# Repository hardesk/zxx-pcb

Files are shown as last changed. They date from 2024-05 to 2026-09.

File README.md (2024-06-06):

# Caravel with Z80 to DIP40 adapter PCB

See: https://github.com/rejunity/z80-open-silicon

## Pinout

                                   Z80 CPU
                   ,----------------.___.----------------.
      <--    A11  1| io[19] 57                 55 io[18] |40 A10    -->
      <--    A12  2| io[20] 58                 54 io[17] |39 A9     -->
      <--    A13  3| io[21] 59                 53 io[16] |38 A8     -->
      <--    A14  4| io[22] 60                 51 io[15] |37 A7     -->
      <--    A15  5| io[23] 61                 50 io[14] |36 A6     -->
      -->    CLK  6|  XCLK  22                 48 io[13] |35 A5     -->
      <->     D4  7| io[24] 62                 42 io[ 8] |34 A4     -->
      <->     D3  8| io[25]  2                 43 io[ 9] |33 A3     -->
      <->     D5  9| io[26]  3                 44 io[10] |32 A2     -->
      <->     D6 10| io[27]  4                 46 io[12] |31 A1     -->
         VCC_5V0 11|               Caravel     45 io[11] |30 A0     -->
      <->     D2 12| io[28]  5       pins                |29 GND
      <->     D7 13| io[29]  6                 41 io[ 7] |28 /RFSH  -->
      <->     D0 14| io[31]  8                 33 io[ 2] |27 /M1    -->
      <->     D1 15| io[30]  7                 21 io[ 0] |26 /RESET <--
      -->   /INT 16| io[33] 12                 34 io[37] |25 /BUSRQ <--
      -->   /NMI 17| io[32] 11                 37 io[ 6] |24 /WAIT  <--
      <--  /HALT 18| io[34] 31                 32 io[ 1] |23 /BUSAK -->
      <--  /MREQ 19| io[35] 13                 36 io[ 5] |22 /WR    -->
      <--  /IORQ 20| io[36] 14                 35 io[ 4] |21 /RD    -->
                   `-------------------------------------'

## Power rails for Caravel
        GND     29 (Z80) --- vss*               56, 52, 38, 39, 29, 23, 20, 10, 1
        VCC_5V0 11 (Z80) --- vddio              64, 17
        VCC_1V8    (LDO) --- vccd, vccd1, vccd2 63, 49, 18

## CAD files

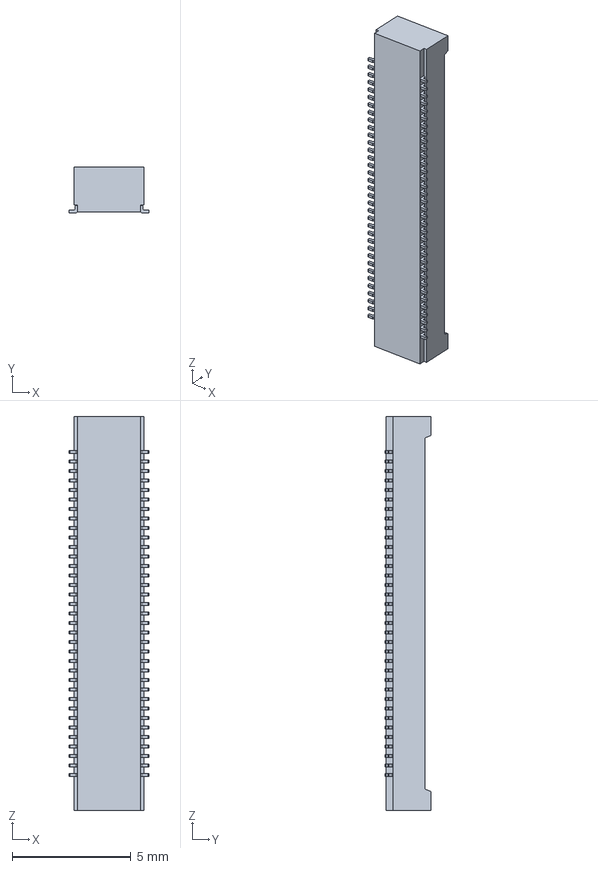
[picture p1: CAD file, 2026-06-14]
mezzanine-dip40/3dmodels/DF40C(2.0)-70DS.stp
3.38 x 1.95 x 16.6 mm

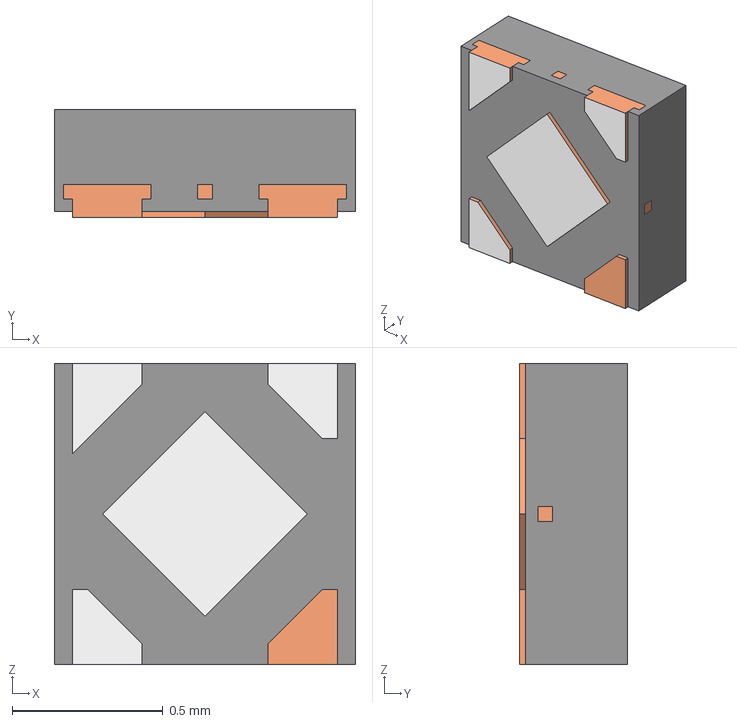
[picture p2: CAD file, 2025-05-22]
z80_qfn64dip/3dmodels/DQN0004A.stp
1.00 x 0.36 x 1.00 mm
MOLD-SNB04A
FRAME-SNB04A

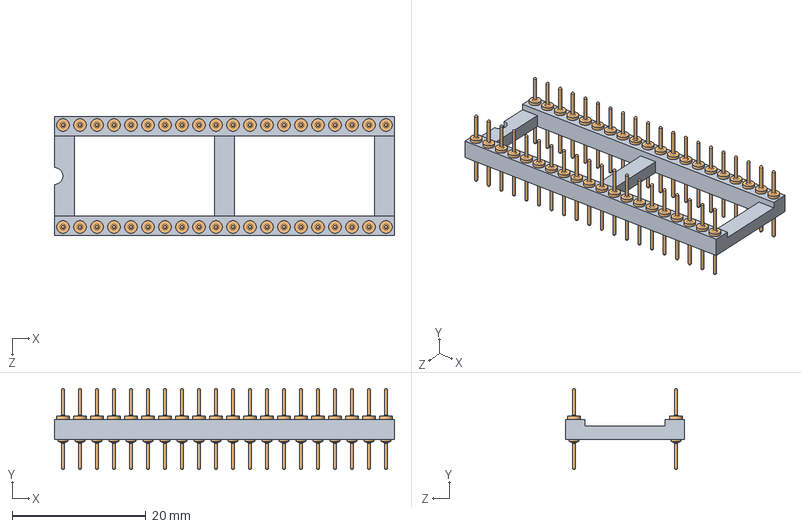
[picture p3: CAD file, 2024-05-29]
z80_qfn64dip/3dmodels/220-1-40-006 3D.STEP
50.8 x 12.1 x 17.8 mm
801-2227P-40-06
802-2227P-GPIN x 40

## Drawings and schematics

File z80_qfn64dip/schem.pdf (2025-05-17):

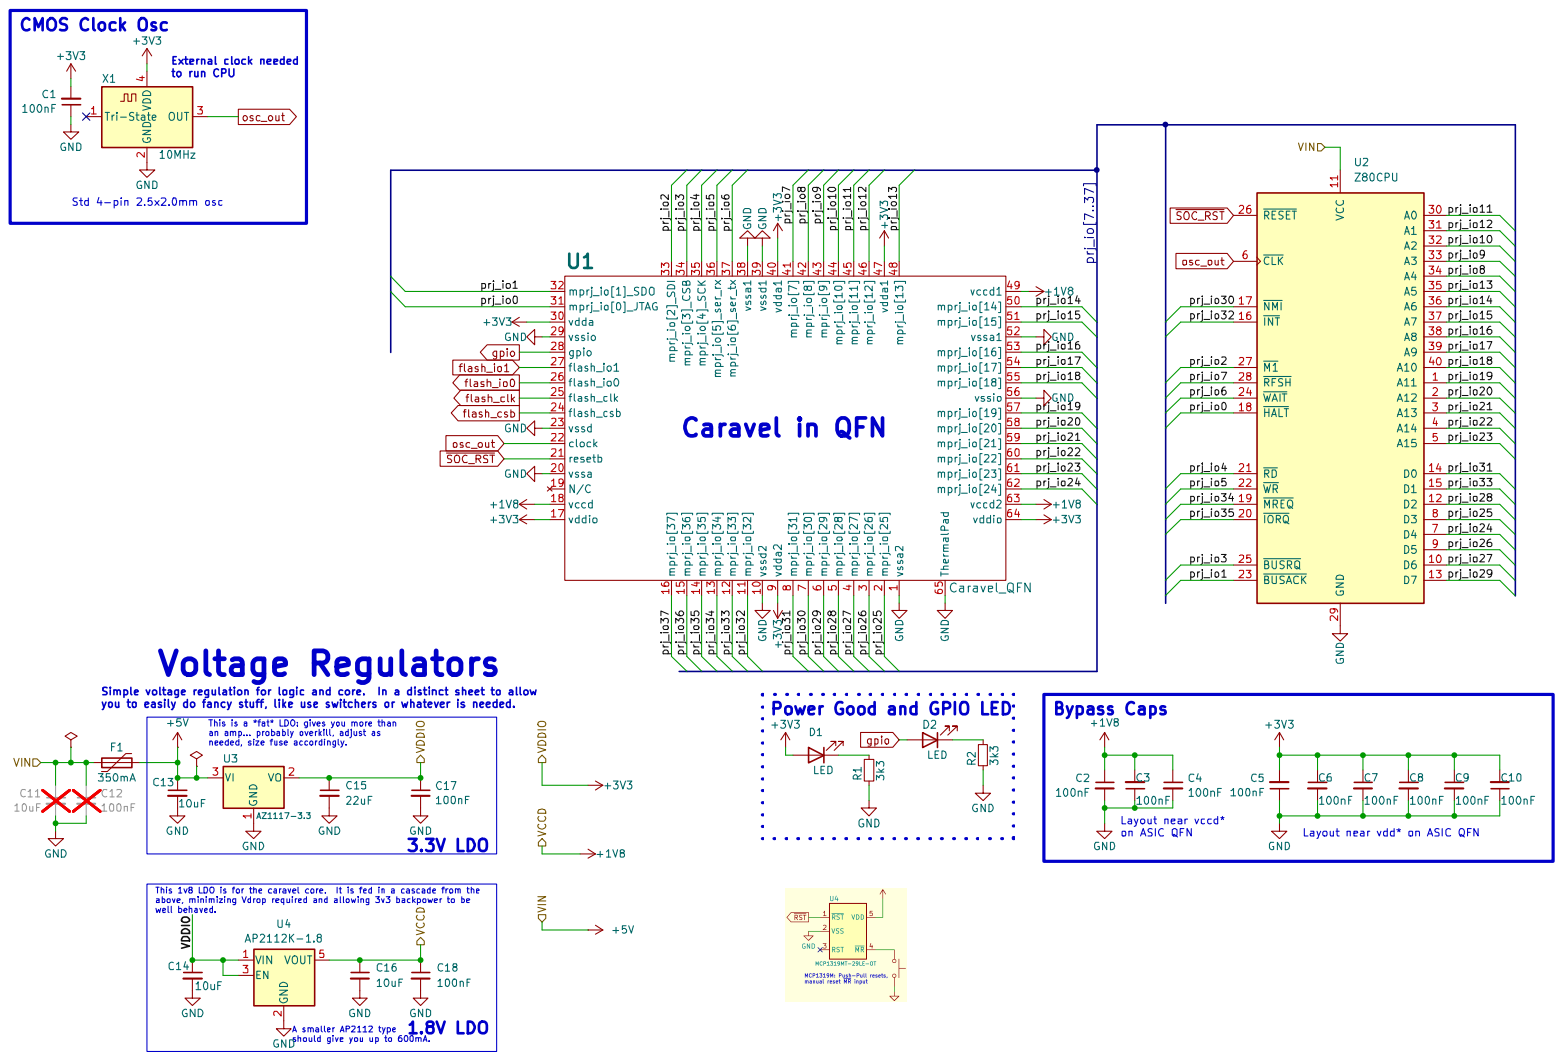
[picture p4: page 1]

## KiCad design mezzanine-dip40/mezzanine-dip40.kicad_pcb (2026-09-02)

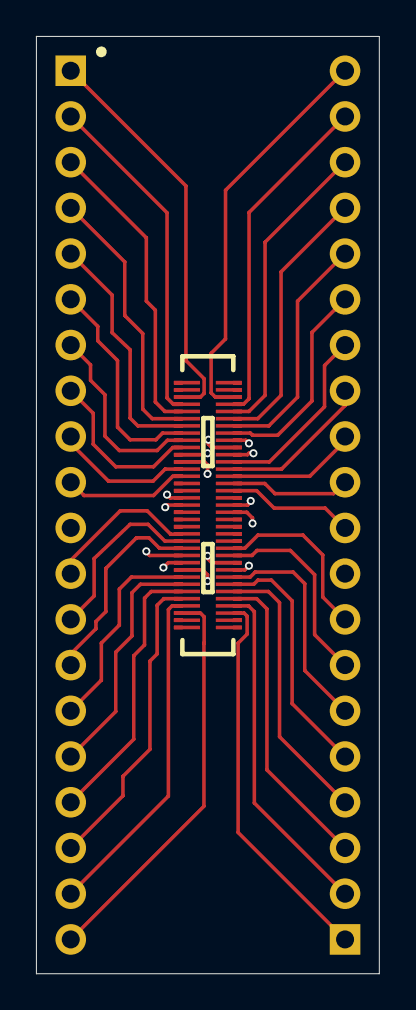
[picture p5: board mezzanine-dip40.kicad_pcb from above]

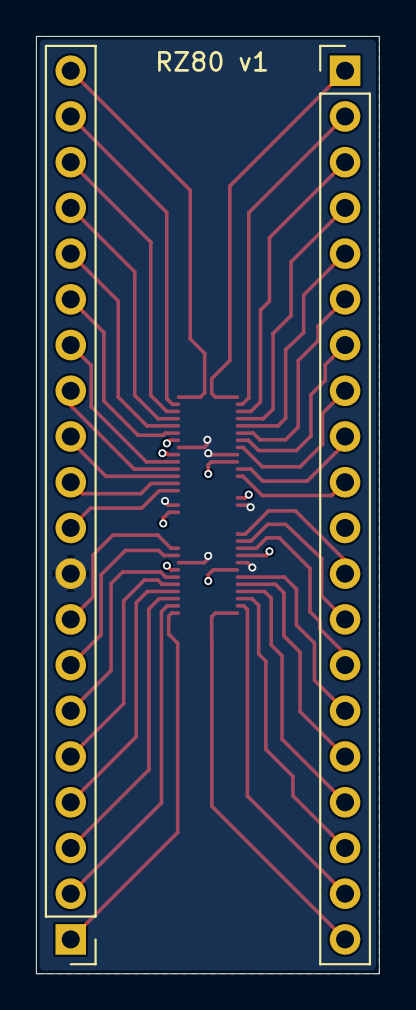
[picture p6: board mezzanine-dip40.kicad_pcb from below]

Board: 4 copper layers, 19.0 x 52.1 mm, 3 parts (2 on the bottom side), 40 nets.

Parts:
J1, J2: Conn_01x20; PinHeader_1x20_P2.54mm_Vertical
U2: CONN-SMD_70P-P0.40_HCTL_HC-PBB40C-70DS-0.4V-xx-02

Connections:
A_{0}: J2.10, U2.51 (pad_28)
A_{1}: J2.11, U2.50 (pad_29)
A_{2}: J2.12, U2.49 (pad_30)
A_{3}: J2.13, U2.48 (pad_31)
A_{4}: J2.14, U2.47 (pad_32)
A_{5}: J2.15, U2.43 (pad_37)
A_{6}: J2.16, U2.42 (pad_38)
A_{7}: J2.17, U2.41 (pad_39)
A_{8}: J2.18, U2.40 (pad_40)
A_{9}: J2.19, U2.39 (pad_41)
A_{10}: J2.20, U2.38 (pad_42)
A_{11}: J1.1, U2.33 (pad_48)
A_{12}: J1.2, U2.32 (pad_49)
A_{13}: J1.3, U2.31 (pad_50)
A_{14}: J1.4, U2.30 (pad_51)
A_{15}: J1.5, U2.29 (pad_52)
CLK: J1.6, U2.28 (pad_53)
D_{0}: J1.14, U2.12 (pad_69)
D_{1}: J1.15, U2.8 (pad_0)
D_{2}: J1.12, U2.14 (pad_67)
D_{3}: J1.8, U2.26 (pad_55)
D_{4}: J1.7, U2.27 (pad_54)
D_{5}: J1.9, U2.23 (pad_58)
D_{6}: J1.10, U2.22 (pad_59)
D_{7}: J1.13, U2.13 (pad_68)
GND: J2.9, U2.10 (GND), U2.18 (GND), U2.25 (GND), U2.45 (GND), U2.53 (GND), U2.61 (GND)
VCC: J1.11, U2.9 (VDD_IO), U2.11 (VDD_CORE), U2.19 (PWR_AUX), U2.24 (VDD_IO), U2.44 (VDD_IO), U2.46 (VDD_CORE), U2.54 (PWR_AUX), U2.62 (VDD_IO)
~BUSACK: J2.3, U2.66 (pad_13)
~BUSRQ: J2.5, U2.64 (pad_15)
~HALT: J1.18, U2.5 (pad_3)
~INT: J1.16, U2.7 (pad_1)
~IORQ: J1.20, U2.3 (pad_5)
~M1: J2.7, U2.60 (pad_19)
~MREQ: J1.19, U2.4 (pad_4)
~NMI: J1.17, U2.6 (pad_2)
~RD: J2.1, U2.68 (pad_11)
~RESET: J2.6, U2.63 (pad_16)
~RFSH: J2.8, U2.59 (pad_20)
~WAIT: J2.4, U2.65 (pad_14)
~WR: J2.2, U2.67 (pad_12)

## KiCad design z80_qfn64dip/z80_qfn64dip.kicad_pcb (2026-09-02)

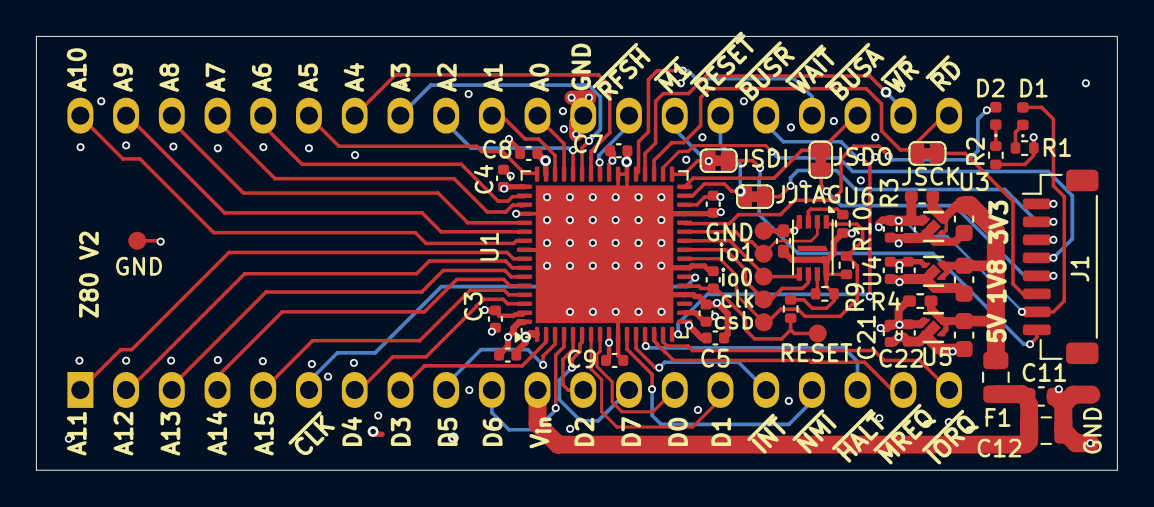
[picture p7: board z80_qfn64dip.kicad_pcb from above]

Board: 4 copper layers, 60.1 x 24.1 mm, 52 parts (0 on the bottom side), 59 nets.

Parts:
C2, C3, C4, C5, C6, C7, C8, C9, C10, C18, C22, C26: 100nF; C_0402_1005Metric
C11: 10uF; C_0805_2012Metric
C12: 100nF; C_0603_1608Metric
C16, C23, C24: 4.7uF; C_0603_1608Metric
C17, C21, C25: 4.7uF; C_0402_1005Metric
C19: 1uF; C_0402_1005Metric
C20: 100nF; C_0402_1005Metric_Pad0.74x0.62mm_HandSolder
D1, D2: LED; LED_0402_1005Metric
F1: 350mA; Fuse_0805_2012Metric
J1: Conn_08; JST_SH_BM08B-SRSS-TB_1x08-1MP_P1.00mm_Vertical
JP1: JSDI; SolderJumper-2_P1.3mm_Bridged_RoundedPad1.0x1.5mm_Small_Mar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
JP2: JSCK; SolderJumper-2_P1.3mm_Bridged_RoundedPad1.0x1.5mm_Small_Mar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
JP3: JJTAG; SolderJumper-2_P1.3mm_Bridged_RoundedPad1.0x1.5mm_Small_Mar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
JP5: JSDO; SolderJumper-2_P1.3mm_Bridged_RoundedPad1.0x1.5mm_Small_Mar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
R1, R2: 4k7; R_0402_1005Metric
R3, R4: 0R; R_0402_1005Metric_Pad0.72x0.64mm_HandSolder
R9, R10, R11, R12: 10k; R_0402_1005Metric
TP9: io1; TestPoint_Pad_D1.0mm
TP10: io0; TestPoint_Pad_D1.0mm
TP11: clk; TestPoint_Pad_D1.0mm
TP12: csb; TestPoint_Pad_D1.0mm
TP13: GND; TestPoint_Pad_D1.0mm
TP14: RESET; TestPoint_Pad_D1.0mm_Small_Margin
TP15, TP16: GND; TestPoint_Pad_D1.0mm_Small_Margin
U1: Caravel_QFN; QFN-64-1EP_9x9mm_P0.5mm_EP7.65x7.65mm
U2: Z80CPU; IC_ADAPTER_ 220-1-40-006
U3: TPS7A2033PDQNRM3; DQN0004A-MFG
U4: TPS7A2018PDQNRM3; DQN0004A-MFG
U5: TPS7A2050PDQNRM3; DQN0004A-MFG
U6: AT25EU0081A; UDFN-8-1EP-2x3mm_P0.5mm_EP1.6x0.2mm

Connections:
/HKJTAG: J1.2, JP3.2 (B)
/HKSCK: J1.6, JP2.2 (B)
/HKSDI: J1.8, JP1.2 (B)
/HKSDO: J1.5, JP5.1 (A)
/VIN: C11.1, C12.1, F1.1, U2.11 (VCC)
/VIN_{F}: C16.1, C23.1, C24.1, F1.2, R3.1, R4.1, U3.3 (EN), U3.4 (IN), U4.3 (EN), U4.4 (IN), U5.3 (EN), U5.4 (IN)
/prj_io7: U1.41 (mprj_io[7]), U2.28 (~RFSH)
/prj_io8: U1.42 (mprj_io[8]), U2.34 (A4)
/prj_io9: U1.43 (mprj_io[9]), U2.33 (A3)
/prj_io10: U1.44 (mprj_io[10]), U2.32 (A2)
/prj_io11: U1.45 (mprj_io[11]), U2.30 (A0)
/prj_io12: U1.46 (mprj_io[12]), U2.31 (A1)
/prj_io13: U1.48 (mprj_io[13]), U2.35 (A5)
/prj_io14: U1.50 (mprj_io[14]), U2.36 (A6)
/prj_io15: U1.51 (mprj_io[15]), U2.37 (A7)
/prj_io16: U1.53 (mprj_io[16]), U2.38 (A8)
/prj_io17: U1.54 (mprj_io[17]), U2.39 (A9)
/prj_io18: U1.55 (mprj_io[18]), U2.40 (A10)
/prj_io19: U1.57 (mprj_io[19]), U2.1 (A11)
/prj_io20: U1.58 (mprj_io[20]), U2.2 (A12)
/prj_io21: U1.59 (mprj_io[21]), U2.3 (A13)
/prj_io22: U1.60 (mprj_io[22]), U2.4 (A14)
/prj_io23: U1.61 (mprj_io[23]), U2.5 (A15)
/prj_io24: U1.62 (mprj_io[24]), U2.7 (D4)
/prj_io25: U1.2 (mprj_io[25]), U2.8 (D3)
/prj_io26: U1.3 (mprj_io[26]), U2.9 (D5)
/prj_io27: U1.4 (mprj_io[27]), U2.10 (D6)
/prj_io28: U1.5 (mprj_io[28]), U2.12 (D2)
/prj_io29: U1.6 (mprj_io[29]), U2.13 (D7)
/prj_io30: U1.7 (mprj_io[30]), U2.15 (D1)
/prj_io31: U1.8 (mprj_io[31]), U2.14 (D0)
/prj_io32: U1.11 (mprj_io[32]), U2.17 (~NMI)
/prj_io33: U1.12 (mprj_io[33]), U2.16 (~INT)
/prj_io34: U1.13 (mprj_io[34]), U2.18 (~HALT)
/prj_io35: U1.14 (mprj_io[35]), U2.19 (~MREQ)
/prj_io36: U1.15 (mprj_io[36]), U2.20 (~IORQ)
/prj_io37: U1.16 (mprj_io[37]), U2.25 (~BUSRQ)
GND: C2.2, C3.1, C4.2, C5.1, C6.2, C7.2, C8.2, C9.2, C10.1, C11.2, C12.2, C16.2, C17.2, C18.2, C19.2, C20.2, C21.2, C22.2, C23.2, C24.2, C25.2, C26.2, J1.1, J1.3, R1.2, R2.2, TP13.1, TP15.1, TP16.1, U1.1 (vssa2), U1.10 (vssd2), U1.20 (vssa), U1.23 (vssd), U1.29 (vssio), U1.38 (vssa1), U1.39 (vssd1), U1.52 (vssa1), U1.56 (vssio), U1.65 (ThermalPad), U2.29 (GND), U3.2 (GND), U3.5 (Thermal_Pad), U4.2 (GND), U4.5 (Thermal_Pad), U5.2 (GND), U5.5 (Thermal_Pad), U6.4 (GND)
HK_CSB: J1.4, U1.34 (mprj_io[3]_CSB)
HK_JTAG: JP3.1 (A), U1.31 (mprj_io[0]_JTAG), U2.26 (~RESET)
HK_SCK: JP2.1 (A), U1.35 (mprj_io[4]_SCK), U2.21 (~RD)
HK_SDI: JP1.1 (A), U1.33 (mprj_io[2]_SDI), U2.27 (~M1)
HK_SDO: JP5.2 (B), U1.32 (mprj_io[1]_SDO), U2.23 (~BUSACK)
unnamed: D1.1 (K), R1.1
unnamed: D2.1 (K), R2.1
unnamed: R11.1, U6.7 (~HOLD(IO_{3}))
unnamed: R10.1, U6.3 (~WP(IO_{2}))
VCCD: C2.1, C3.2, C4.1, C17.1, C18.1, U1.18 (vccd), U1.49 (vccd1), U1.63 (vccd2), U4.1 (OUT)
VDDA: C6.1, C7.1, C8.1, C9.1, C20.1, C25.1, C26.1, D1.2 (A), J1.7, R3.2, R9.1, R10.2, R11.2, R12.1, U1.9 (vdda2), U1.30 (vdda), U1.40 (vdda1), U1.47 (vdda1), U3.1 (OUT), U6.8 (Vcc)
VDDIO: C5.2, C10.2, C21.1, C22.1, R4.2, U1.17 (vddio), U1.64 (vddio), U5.1 (OUT)
flash_clk: TP11.1, U1.25 (flash_clk), U6.6 (SCK)
flash_csb: R9.2, TP12.1, U1.24 (flash_csb), U6.1 (~CS)
flash_io0: TP10.1, U1.26 (flash_io0), U6.5 (SI(IO_{0}))
flash_io1: TP9.1, U1.27 (flash_io1), U6.2 (SO(IO_{1}))
gpio: D2.2 (A), U1.28 (gpio)
osc_out: U1.22 (clock), U2.6 (~CLK)
ser_rx: U1.36 (mprj_io[5]_ser_rx), U2.22 (~WR)
ser_tx: U1.37 (mprj_io[6]_ser_tx), U2.24 (~WAIT)
~SOC_RST: C19.1, R12.2, TP14.1, U1.21 (resetb)

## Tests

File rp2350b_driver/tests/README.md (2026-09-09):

# WAIT bus regression

The hardware trace test requires `request.dump()` enabled in the main loop,
before `write_reply()`. Normal firmware may leave that call commented out.
RTT uses blocking mode, so a stopped debugger can hold a request indefinitely.
The bus PIO must keep WAIT asserted and issue exactly one request per transfer.

The revised 32-word PIO program:

- Qualifies `(MREQ || IORQ) && (RD || WR)` from one GPIO image, testing
  MREQ/IORQ first. A second qualified sample after another clock supplies the
  request, with WAIT asserted throughout.
- Sets read data and direction before releasing WAIT at a settled falling
  clock phase. The independent clock SM keeps running during logging.
- Checks MREQ, IORQ, RD and WR together, continuously, until **two consecutive
  samples** show all four inactive. It then releases data and re-arms WAIT.
  A single strobe transition, including WR pulses during Tw, cannot end a cycle.

Do not replace completion detection with one sample per clock: the inactive
gap around refresh can last only half a clock. The GPIO/DMA capture caught
that approach missing the gap, leaving WAIT high through the next operand read.
Do not deduplicate by address: two legitimate reads may use the same address.

The `[15]` delays assume the board's 150 MHz system clock and allow the Tang
external-clock synchronizer to settle. The driver requires at least 40 PIO
ticks per Z80 clock (up to 3.75 MHz at 150 MHz). This is a board timing budget,
not a claim of compatibility with every external Z80 implementation.

## Instruction-level regression

```sh
make test-wait-pio
```

The test interprets the actual PIO source. It checks 42 clock phases and eight
reply delays, with startup reset, refresh rejection, short strobe glitches,
WR pulses during waits, read/write turnaround, I/O, and repeated-address reads.
It checks request count, data direction, data setup, and WAIT re-arming.
This digital model does not model FPGA propagation delay or metastability.

## Hardware regression

Before building the hardware test, enable `request.dump()` in `main.cpp`, set
`prog_org` to `0x100`, and select the stress program in `CMakeLists.txt`:

```cmake
set(DATA_ASM ${CMAKE_CURRENT_SOURCE_DIR}/tests/wait_bus_stress.asm)
```

Replace the existing active `DATA_ASM` selection for this test. An unconditional
`set(DATA_ASM ...)` overrides a command-line `-DDATA_ASM=...` cache value.
Keep these test-only source changes out of the normal firmware commit, and use
a separate build directory:

```sh
cmake -S . -B derived/wait_regression \
  -DPICO_SDK_PATH=/Users/orl/Projects/pico-sdk \
  -DCMAKE_BUILD_TYPE=Release -DZ80_BUS_MODE=WAIT \
  -DZ80_CLOCK_HZ=3500000 -DZ80_REPLY_DELAY_US=0
cmake --build derived/wait_regression --parallel
```

Run `make openocd` in another terminal. The following command **flashes the
attached RP2350**, verifies it, resets it, and captures RTT. No FPGA bitstream
is changed.

```sh
python3 tests/capture_wait_trace.py \
  derived/wait_regression/rp2350_driver.elf \
  derived/wait_regression/trace.log \
  --seconds 45 --pause-every 2 --pause-seconds 0.5 --poll-ms 1
python3 tests/check_wait_trace.py \
  derived/wait_regression/wait_bus_stress.bin \
  derived/wait_regression/trace.log
```

Pauses stop **OpenOCD RTT polling**, rather than just TCP reads, so socket
buffers cannot hide the intended blocking-printf stall. All complete trace
lines are checked from the reset vector onwards. The checker compares address,
M1, request/transfer controls, memory contents and write data with an independent
execution of the small stress program. Conditional branches also check that the
CPU actually received the read data. Each loop has 65 bus requests and includes
two reads of the same memory location, memory writes and I/O reads/writes.

Set `-DZ80_REPLY_DELAY_US=10000` to add a deterministic varying 0–10 ms delay
before every reply. Use `-DZ80_WAIT_CAPTURE=ON` to capture GPIO0..31 with PIO2
and DMA around the first eight replies; `sample` indices are four system-clock
ticks apart (26.67 ns at 150 MHz). Captures perturb host reply timing and are
diagnostics, not the final stress qualification. Capture records are ignored
by the bus-trace checker.

Restore the normal program selection, load address and logging setting, then
rebuild and reflash the normal firmware after testing. See `wait_results.md` for the
recorded board results and remaining validation limits.

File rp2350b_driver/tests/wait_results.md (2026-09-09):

# Board results — 2026-09-08

Tests used the attached RP2350/CMSIS-DAP board, the existing FPGA configuration,
150 MHz RP2350 system clock, WAIT backend, and blocking `request.dump()` before
every reply. The FPGA was not reprogrammed. Raw traces and test ELFs are in
`derived/wait_stress/` (build artifacts, not source-controlled).

The starting PIO failed at request 2 in `baseline.log`:

```text
busreq 0000 55 m1 1 mreq 1 ioreq 0 rd 1 wr 0 mem c3
busreq 0000 c3 m1 0 mreq 1 ioreq 0 rd 1 wr 0 mem c3
```

The second request should have been the operand at `0001`. Adding a second
qualification sample alone also failed (request 208, `settle.log`). A version
that sampled cycle completion once per clock skipped transfers; the DMA trace
in `aligned_capture.log` shows WAIT remaining high through the `0001` read
after the reset opcode reply. That experiment was rejected.

The final program uses continuous, coherent, twice-confirmed idle detection
and keeps the extra qualification sample and clock-aligned reply release.
The trace checker passed these runs with no extra/missing requests, incorrect
controls, or incorrect memory/write data:

| Build / Z80 clock | Host delay | Checked requests | Complete loops | Trace |
|---|---|---:|---:|---|
| Release / 3.5 MHz | RTT pauses of 250 ms | 3,734 | 57 | `continuous_end.log` |
| Release / 3.5 MHz | RTT pauses of 500 ms, 45 s run | 73,721 | 1,134 | `final_3500k.log` |
| Release / 3.5 MHz | Varying 0–10 ms per reply + 500 ms RTT pauses | 4,888 | 75 | `final_delay10ms.log` |
| Release / 100 kHz | RTT pauses of 500 ms | 34,529 | 531 | `final_100k.log` |
| Debug / 3.75 MHz | RTT pauses of 500 ms | 41,314 | 635 | `final_3750k_debug.log` |

Total: **158,186 checked requests, 2,432 complete loops**. Each trace starts
from a fresh verified firmware flash/reset; no trace prefix was discarded.

The source-interpreting PIO regression also passed all 336 reply-delay/clock-
phase combinations. It is a digital handshake test, not an electrical model.

Finally, `derived/drv_dbg/rp2350_driver.elf` was rebuilt, flashed and verified
with the original ZEXALL image, Debug, 3.5 MHz, zero injected reply delay and
GPIO capture disabled. Its generated PIO instructions match the stress-tested
program. `normal_zexall.log` records 20,762 requests, the correct reset-vector
sequence, and the ZEXALL startup banner. The main-loop dump was enabled for
that recorded run.

These tests validate memory fetch/read/write and I/O read/write under delayed
replies. They do not constitute a complete ZEXALL run or an interrupt-acknowledge,
physical BUSRQ/DMA, or reset-during-transaction qualification.

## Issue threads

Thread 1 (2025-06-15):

Questions about circuit

psychogenic, 2025-06-15:
Greets,
At Rej's request, I'm doing a mini review and proto run of these boards.  I have to look back at the old caravel boards to make sure that that "poor man's" reset circuit (a cap) was actually working w/o explicit pull-up (I think there's an internal, will check).  It's all a bit fuzzy (haven't played with caravel in a while) but the two first things that popped out to me are:

  *  I've never pushed VDDIO to the abs max of 5V--you know this is ok, or are just sticking to the fact that it's the listed maximum?  an
  *  If VDDIO is 5V, are we certain the pins going to the external flash are running at VDDA of 3v3?

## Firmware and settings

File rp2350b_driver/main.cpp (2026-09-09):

#include <cstddef>
#include <cstdint>
#include <cstring>
#include <cstdio>
#include <algorithm>
// #include <memory>

#include <pico/stdlib.h>
#include <pico/stdio.h>
#include <hardware/gpio.h>

#include "z80_pins.hpp"
#include "z80_pio_bus.hpp"
#ifdef Z80_WAIT_CAPTURE
#include "tests/wait_capture.hpp"
#endif

using std::size_t;

#define PIN_DEBUG 1

#define IO_DATA_SHIFT 0
#define IO_DATA 0x0000'00ffu
#define IO_ADDR_SHIFT 8
#define IO_ADDR 0x00ff'ff00u
#define IO_CTRL 0x1f'ff00'0000ull
#define IO_CTRL_SHIFT 24
#define IO_CTRLL_WIDTH 8
#define IO_CTRLH_WIDTH 5
#define IO_ALL ((uint64_t)IO_DATA|(uint64_t)IO_ADDR|(uint64_t)IO_CTRL)

inline uint32_t extract_ctrl(uint64_t ctrl_addr_data) {
    return (ctrl_addr_data & IO_CTRL) >> IO_CTRL_SHIFT;
}

inline uint32_t extract_ctrl(uint32_t ctrl_addr_data, uint32_t ctrlhi) {
    uint32_t lo = (ctrl_addr_data & IO_CTRL) >> IO_CTRL_SHIFT;
    uint32_t hi = ctrlhi & (IO_CTRL >> 32);
    return lo | (hi << IO_CTRLL_WIDTH);
}

struct ZxDbgPins
{
    uint16_t addr;
    uint8_t data;
    union {
        struct {
            bool CLK:1, RESET:1, WAIT:1, M1:1, MREQ:1, IORQ:1, RD:1, WR:1,
                 INT:1, NMI:1, BUSREQ:1, BUSACK:1, HALT:1;
        };
        uint16_t value;
    } pins;

    ZxDbgPins(uint32_t lo, uint32_t hi) {
        addr = (lo & IO_ADDR) >> IO_ADDR_SHIFT;
        data = (lo & IO_DATA) >> IO_DATA_SHIFT;
        pins.value = extract_ctrl(lo, hi);
    }

    ZxDbgPins(uint64_t v) {
        addr = (v & IO_ADDR) >> IO_ADDR_SHIFT;
        data = (v & IO_DATA) >> IO_DATA_SHIFT;
        pins.value = extract_ctrl(v);
    }

    void dump_state(unsigned T) {
        printf("T%4d %04x %02x clk %d rst %d mreq %d m1 %d iorq %d rd %d wr %d int %d halt %d wait %d nmi %d busreq %d busack %d\n",
            T, addr, data,
            pins.CLK, pins.RESET, pins.MREQ, pins.M1, pins.IORQ, pins.RD, pins.WR,
            pins.INT, pins.HALT, pins.WAIT, pins.NMI, pins.BUSREQ, pins.BUSACK
        );
    }
};

template<class DerivedT>
struct ZxEnv
{
    // typedef uint8_t (*f_io_read_t)(uint16_t addr);
    // typedef void (*f_io_write_t)(uint16_t addr, uint8_t data);

    DerivedT& self() { return *static_cast<DerivedT*>(this); }

    char* m_ram;
    size_t m_ram_size;

    #define DAT(x) ((addr_data&IO_DATA)>>IO_DATA_SHIFT)
    #define ADR(x) ((addr_data&IO_ADDR)>>IO_ADDR_SHIFT)

    #define IS_LO(pin,bits) ((bits & (1U<<(pin-IO_CTRL_SHIFT))) == 0)
    #define IS_HI(pin,bits) ((bits & (1U<<(pin-IO_CTRL_SHIFT))) != 0)

    uint16_t m_ctrl_prev = (uint16_t)(IO_CTRL>>IO_CTRL_SHIFT);

    uint8_t peek(uint16_t addr) const { return m_ram[addr]; }

    // ctrl is shifted to 0 bits
    void react(uint16_t ctrl, uint32_t addr_data) {
        uint32_t ctrlx = m_ctrl_prev ^ ctrl; // =1 which signal changed
        m_ctrl_prev = ctrl;

        // MEMORY ACCESS
        if (IS_LO(pMREQ, ctrl)) {
            // CPU WRITEs
            if (IS_LO(pWR, ctrl) && IS_HI(pWR, ctrlx)) {
                uint16_t addr = ADR(addr_data);
                uint8_t dat = DAT(addr_data);
                self().impl_debug_trap(addr, dat);
                self().impl_on_memwrite(addr, dat);
                m_ram[addr] = dat;
            } else
            // CPU READs
            if (IS_LO(pRD, ctrl) && IS_HI(pRD, ctrlx)) {
                uint16_t addr = ADR(addr_data);
                uint8_t dat = m_ram[addr];
                self().impl_on_memread(addr, IS_LO(pM1, ctrl));
                if (IS_LO(pM1, ctrl)) {
                    // printf("\033[34mcode %04x %02x\033[0m\n", addr, dat);
                    if (addr==0)
                        printf("\033[31mSOFT RESET DETECTED\033[0m\n");
                }
                self().expose_data(dat);
            }
        } else
        // CPU done reading/writing memory
        if (IS_HI(pMREQ, ctrl) && IS_HI(pMREQ, ctrlx)) {
            self().clear_data_bus();
        }
        // IO ACCESS
        if (IS_LO(pIORQ, ctrl)) {
            // CPU WRITEs IO
            if (IS_LO(pWR, ctrl) && IS_HI(pWR, ctrlx)) {
                uint16_t addr = ADR(addr_data);
                uint8_t dat = DAT(addr_data);
                self().handle_io_out(addr, dat);
            } else
            // CPU READs IO
            if (IS_LO(pRD, ctrl) && IS_HI(pRD, ctrlx)) {
                uint16_t addr = ADR(addr_data);
                uint8_t dat = self().handle_io_in(addr);
                self().expose_data(dat);
            }
        } else
        // CPU done reading/writing IO
        if (IS_HI(pIORQ, ctrl) && IS_HI(pIORQ, ctrlx)) {
            self().clear_data_bus();
        }
    }

    struct MemoryDumpOpts {
        short width = 16;
        bool show_address:1 = true;
        bool ascii:1 = false;
    };

    void dump_memory(unsigned addr, size_t size, MemoryDumpOpts opts = MemoryDumpOpts()) {
        for (size_t i=0; i<size; ) {
            char const* pl = m_ram + addr + i;
            size_t mx = std::min(size-i, (size_t)opts.width);
            if (opts.show_address)
                printf("%08x  ", addr + i);
            for (size_t q=0; q<mx; ++q)
                printf("%02x%s", pl[q], q == mx-1 ? "" : " ");
            printf("%*s", 1 + (opts.width-mx)*3, "");
            if (opts.ascii) {
                printf("%c", ' ');
                for (size_t q=0; q<mx; ++q)
                    printf("%c", pl[q] >= 32 && pl[q] <= 127 ? pl[q] : '.' );
            }
            printf("\n");
            i += mx;
        }
    }

protected:
    void impl_debug_trap(uint16_t addr, uint8_t trapno) {}

    void impl_on_memread(uint16_t addr, bool m1) {}
    void impl_on_memwrite(uint16_t addr, uint8_t dat) {}
};

struct Rp2350ZxEnv : public ZxEnv<Rp2350ZxEnv>
{
    template<class T> friend class ZxEnv;

    Rp2350ZxEnv() {
        m_ram_size = 256*256;
        m_ram = new char[m_ram_size];
        memset(m_ram, 0, m_ram_size);
    }

    ~Rp2350ZxEnv() {
        delete[] m_ram;
    }
    
    static constexpr uint64_t kInitialHighPins =
        (1ull << pINT) | (1ull << pWAIT) | (1ull << pNMI) | (1ull << pBUSRQ);
    static constexpr uint16_t CPM_TRAP_TRIGGER = 0x03;
    static constexpr uint16_t CPM_TRAP_CODE = 0xffe0; // Note: zexall sets SP to address at (6)
    static constexpr uint16_t CPM_TRAP_STORE = 0xfff0;

    void init() {
        uint64_t pins_oe = 
            (1ull << pCLK)     |
            (1ull << pRESET)   |
            (1ull << pINT)     |
            (1ull << pWAIT)    |
            (1ull << pNMI)     |
            (1ull << pBUSRQ) 
            ;
        for(int i=0; i<pPIN_COUNT; ++i)
            gpio_set_pulls(i, false, false);
        gpio_set_function_masked64(IO_ALL, GPIO_FUNC_SIO);

        // Set the output latches before enabling them. RESET and CLK start
        // low; interrupt inputs, WAIT and BUSRQ start inactive (high).
        gpio_put_all64(kInitialHighPins);
        gpio_set_dir_all_bits64(pins_oe);
    }

    void expose_data(uint8_t dat) {
        // gpio_set_dir_out_masked(IO_LOW_OUT | IO_DATA);
        gpio_set_dir_masked(IO_DATA, IO_DATA);
        gpio_put_masked(IO_DATA, dat << IO_DATA_SHIFT);
    }

    void clear_data_bus() {
        // gpio_set_dir_out_masked(IO_LOW_OUT);
        gpio_set_dir_masked(IO_DATA, 0);
    }

    void handle_io_out(uint16_t addr, uint8_t data) {
        if (addr == 0xff81) {
            printf("DATA on port %04x: %02x\n", addr, data);
        } else if (addr == 0xff83) {
            printf("%c", data);
        }
    }
    uint8_t handle_io_in(uint16_t port) {
        return (port & 1) ? 0xFF : 0xBF;
    }

    uint8_t handle_interrupt_ack() { return 0xff; }

    uint32_t service_pio_request(z80pio::BusRequest const& request) {
        const uint16_t addr = request.address();
        const uint8_t data = request.data();

        if (request.mreq() && request.rd()) {
            uint8_t value = static_cast<uint8_t>(m_ram[addr]);
            impl_on_memread(addr, request.m1());
            return z80pio::read_reply(value);
        }

        if (request.mreq() && request.wr()) {
            impl_debug_trap(addr, data);
            impl_on_memwrite(addr, data);
            m_ram[addr] = static_cast<char>(data);
            return z80pio::write_reply();
        }

        if (request.iorq() && request.rd())
            return z80pio::read_reply(handle_io_in(addr));

        if (request.iorq() && request.wr()) {
            handle_io_out(addr, data);
            return z80pio::write_reply();
        }

        if (request.iorq() && request.m1())
            return z80pio::read_reply(handle_interrupt_ack());

        return z80pio::write_reply();
    }

    template<class... Bytes>
    static char* store_bytes(char* p, Bytes... bytes) { ( (*p++ = bytes), ... ); return p; }

    void prepare_vectors(uint16_t jump_on_reset_addr = 0x100) {
        store_bytes( m_ram + 0, 0xc3, jump_on_reset_addr & 0xff, jump_on_reset_addr >> 8);
        store_bytes( m_ram + CPM_TRAP_TRIGGER, 0, 0);

        // hook up to CP/M call 5
        store_bytes(m_ram + 5, 0xc3, CPM_TRAP_CODE, CPM_TRAP_CODE >> 8);    // jp CPM_TRAP_CODE

        // by default 0x100 jumps to 0x8000
        store_bytes(m_ram + 0x100, 0xc3, 0x00, 0x80);    // jp 0x8000

        char* p = m_ram + CPM_TRAP_CODE;
        p = store_bytes(p, 0xed, 0x43, CPM_TRAP_STORE, CPM_TRAP_STORE >> 8);    // ld (CPM_TRAP_STORE+0), bc
        p = store_bytes(p, 0xed, 0x53, CPM_TRAP_STORE+2, CPM_TRAP_STORE >> 8);  // ld (CPM_TRAP_STORE+2), de
        p = store_bytes(p, 0x3e, 0x01);                                 // ld a, 1
        p = store_bytes(p, 0x32, CPM_TRAP_TRIGGER, CPM_TRAP_TRIGGER >> 8);      // ld (CPM_TRAP_TRIGGER), a <-- trigger trap
        p = store_bytes(p, 0xc9);                                       // ret
    }

    void load(unsigned char const* data, size_t size, uint16_t origin) {
        unsigned char* dest = (unsigned char*)m_ram + origin;
        memcpy(dest, data, size);
    }

private:
    void impl_debug_trap(uint16_t addr, uint8_t trapno) {
        if (addr == 4) {
            printf("MEM4 <- %02x\n", trapno);
        }
        if (addr == CPM_TRAP_TRIGGER && trapno == 1) {
            uint8_t c = *(m_ram+CPM_TRAP_STORE+0);
            uint16_t de = *(uint16_t*)(m_ram+CPM_TRAP_STORE+2);
            if (c == 2) {
                uint8_t e = de&0xff;
                printf("%c", e);
            } else if (c==9) {
                char const* str = (char const*)m_ram + de;
                while (*str != '$' && *str != 0) {
                    printf("%c", *str++);
                }
            }
        }
    }

    void impl_on_memwrite(uint16_t addr, uint8_t dat) {
        // if (addr >= 0x1d30 && addr <= 0x1db8) {
        //     printf(">> writing %02x to %04x\n", dat, addr);
        //     dump_memory(0x1d00, 256, { .width = 8, .show_address = true, .ascii = true } );
        // }
    }

};

inline static uint32_t gpio_get_all_hi() {
#if PICO_USE_GPIO_COPROCESSOR
    return gpioc_hi_in_get();
#elif NUM_BANK0_GPIOS <= 32
    return 0;
#else
    return sio_hw->gpio_hi_in;
#endif
}

#define LED_PIN (32+14)

constexpr uint kZ80ResetButtonPin = 40;

void init_z80_reset_button()
{
    gpio_init(kZ80ResetButtonPin);
    gpio_set_dir(kZ80ResetButtonPin, GPIO_IN);
    gpio_pull_up(kZ80ResetButtonPin);
}

bool z80_reset_button_pressed()
{
    return !gpio_get(kZ80ResetButtonPin);
}

void blink_hello() {
    for(size_t i=0; i<10; ++i) {
        gpio_put(LED_PIN, (i&1) == 0);
        sleep_ms(50);
    }
}

struct DebButton {
    static constexpr unsigned POLL_MS = 10;
    DebButton() : next_poll(make_timeout_time_ms(POLL_MS)), last_sample(false), debounced(false) {
    }

    template<class F>
    bool check( F f ) {
        bool pressed = false;
        if (time_reached(next_poll)) {
            next_poll = make_timeout_time_ms(POLL_MS);
            const bool sample = f();
            if (sample == last_sample && sample != debounced)
                pressed = debounced = sample;
            last_sample = sample;
        }
        return pressed;
    }

private:
    absolute_time_t next_poll = 0;
    bool last_sample:1;
    bool debounced:1;
};

#ifdef DATA_ASM_FILE

#if __has_include(DATA_ASM_FILE)
#include DATA_ASM_FILE
#define z80_prog DATA_ASM_LABEL
#endif

#else 

// #if __has_include("zexdoc.h")
// #include "zexdoc.h"
// #define z80_prog zexdoc_prog
// #endif

#if __has_include("test.h")
#include "test.h"
#define z80_prog test_prog
#endif

#endif

// unsigned char copy_str_code[] = {
//   0x11, 0xc0, 0x00, 0x21, 0x0e, 0x01, 0x7e, 0x12, 0x13, 0x23, 0xb7, 0x20,
//   0xf9, 0xc9, 0x48, 0x65, 0x6c, 0x6c, 0x6f, 0x20, 0x57, 0x6f, 0x72, 0x6c,
//   0x64, 0x21, 0x00
// };

int main()
{
    stdio_init_all();

    gpio_set_dir(LED_PIN, true);
    gpio_set_function(LED_PIN, GPIO_FUNC_SIO);
    blink_hello();

    Rp2350ZxEnv zx;
    zx.init();
    init_z80_reset_button();

    // uint16_t prog_org = 0x8000;
    uint16_t prog_org = 0x100;
    zx.prepare_vectors(prog_org);
    zx.load(z80_prog, count_of(z80_prog), prog_org);
    zx.dump_memory(0, 32, { .width = 16, .ascii = true } );
    zx.dump_memory(prog_org, 64, { .width = 16, .ascii = true } );

    printf("Hello from RP2350 over RTT!\n");
    char buf[128];
    auto fmt_pad = [&buf](uint32_t pad) {
        #define GB(x, def) ((x & PADS_BANK0_GPIO0_ ## def ## _BITS) >> PADS_BANK0_GPIO0_ ## def ## _LSB)
        snprintf(buf, sizeof(buf), "iso %d od %d ie %d drive %d pue %d pde %d schmitt %d slewfast %d",
            GB(pad, ISO),
            GB(pad, OD),
            GB(pad, IE),
            GB(pad, DRIVE),
            GB(pad, PUE),
            GB(pad, PDE),
            GB(pad, SCHMITT),
            GB(pad, SLEWFAST));
        return buf;
    };

    // printf("pins oe hi %08x lo %08x func-A0 %d outlevel-A0 %d\n", sio_hw->gpio_hi_oe, sio_hw->gpio_oe, gpio_get_function(pA0), gpio_get_out_level(pA0));
    // printf(" oe h %08x l %08x\n", sio_hw->gpio_hi_oe, sio_hw->gpio_oe);
    // for (int i=0; i<36; ++i){
    //     printf(" - pin %2d func %d oe %d PAD [[ %s ]]\n", i, gpio_get_function(i), gpio_get_dir(i), fmt_pad(pads_bank0_hw->io[i]));
    // }

    constexpr uint32_t kZ80ClockHz = Z80_CLOCK_HZ;
    printf("RZ80 speed %dkHz, bus driver '%s'\n", kZ80ClockHz/1000, z80pio::ActiveBusDriver::id);
    z80pio::ActiveBusDriver bus;
    bus.init(kZ80ClockHz);
    bus.reset_cpu();

    DebButton reset_btn;
#if Z80_REPLY_DELAY_US > 0
    uint32_t delay_state = 1;
#endif
#ifdef Z80_WAIT_CAPTURE
    WaitCapture capture;
    unsigned capture_request = 0;
#endif
    while (true) {
        const z80pio::BusRequest request = bus.read_request();

        // bool reset_requested = reset_btn.check(&z80_reset_button_pressed);

        // Assert RESET before replying so the currently stalled transaction
        // is the last one. Once the reply releases the CPU, the PIO reset
        // guard keeps subsequent samples out of the request FIFO.
        // if (reset_requested)
        //     bus.begin_reset();

        // request.dump(zx.peek(request.address()));

#if Z80_REPLY_DELAY_US > 0
        delay_state = delay_state * 1664525u + 1013904223u;
        busy_wait_us_32(delay_state % (Z80_REPLY_DELAY_US + 1u));
#endif

        const auto reply = zx.service_pio_request(request);
#ifdef Z80_WAIT_CAPTURE
        if (capture_request < 8)
            capture.start();
#endif
        bus.write_reply(reply);
#ifdef Z80_WAIT_CAPTURE
        if (capture_request < 8)
            capture.finish(capture_request++);
#endif

        // if (reset_requested) {
        //     bus.end_reset();
        //     printf("Z80 reset from GPIO40 button\n");
        // }
    }
}

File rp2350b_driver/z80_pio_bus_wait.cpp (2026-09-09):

#include "z80_pio_bus.hpp"

#include <algorithm>

#include <hardware/clocks.h>
#include <hardware/pio.h>
#include <pico/stdlib.h>

#include "z80_bus_wait.pio.h"
#include "z80_pins.hpp"

namespace z80pio {

namespace {

void assign_wait_bus_pins(PIO bus_pio, PIO clock_pio)
{
    for (uint pin = pD0; pin <= pCLK; ++pin) {
        pio_gpio_init(bus_pio, pin);
    }
    for (uint pin = pWAIT; pin <= pWR; ++pin) {
        pio_gpio_init(bus_pio, pin);
    }
    pio_gpio_init(clock_pio, pCLK);
}

} // namespace

void WaitStateBusDriver::init(uint32_t z80_hz)
{
    hard_assert(z80_hz != 0);
    // The sampling delay and two-sample idle filter need this timing budget.
    // At the board's 150 MHz clk_sys this permits up to 3.75 MHz Z80 CLK.
    hard_assert(z80_hz <= clock_get_hz(clk_sys) / 40);

    // The 32-instruction bus program and two-instruction clock program do not
    // fit in one PIO's 32-word instruction memory, so use the other PIO's
    // independent instruction memory for the clock.
    pio_set_gpio_base(bus_pio_, 0);
    pio_set_gpio_base(clock_pio_, 0);
    reset_hold_us_ = std::max<uint32_t>(
        10,
        static_cast<uint32_t>((8'000'000ull + z80_hz - 1) / z80_hz));

    bus_sm_ = pio_claim_unused_sm(bus_pio_, true);
    clock_sm_ = pio_claim_unused_sm(clock_pio_, true);

    const uint bus_offset = pio_add_program(bus_pio_, &z80_wait_bus_program);
    const uint clock_offset = pio_add_program(clock_pio_, &z80_wait_clock_program);

    assign_wait_bus_pins(bus_pio_, clock_pio_);

    pio_sm_config clock_config = z80_wait_clock_program_get_default_config(clock_offset);
    sm_config_set_sideset_pins(&clock_config, pCLK);
    const float clock_divider =
        static_cast<float>(clock_get_hz(clk_sys)) /
        (2.0f * static_cast<float>(z80_hz));
    sm_config_set_clkdiv(&clock_config, std::max(1.0f, clock_divider));

    pio_sm_config bus_config = z80_wait_bus_program_get_default_config(bus_offset);
    sm_config_set_in_pins(&bus_config, pD0);
    sm_config_set_in_pin_count(&bus_config, 32);
    sm_config_set_out_pins(&bus_config, pD0, 8);
    sm_config_set_set_pins(&bus_config, pWAIT, 1);
    sm_config_set_jmp_pin(&bus_config, pRESET);
    sm_config_set_out_shift(&bus_config, true, false, 32);
    sm_config_set_clkdiv(&bus_config, 1.0f);

    pio_sm_init(bus_pio_, bus_sm_, bus_offset, &bus_config);
    pio_sm_init(clock_pio_, clock_sm_, clock_offset, &clock_config);

    pio_sm_set_pins_with_mask(clock_pio_, clock_sm_, 0, 1u << pCLK);
    // Start active so the first transaction cannot outrun request handling.
    // RESET ignores WAIT; the PIO releases it after supplying each response.
    pio_sm_set_pins_with_mask(bus_pio_, bus_sm_, 0, 1u << pWAIT);

    pio_sm_set_consecutive_pindirs(bus_pio_, bus_sm_, pD0, 8, false);
    pio_sm_set_consecutive_pindirs(bus_pio_, bus_sm_, pWAIT, 1, true);
    pio_sm_set_consecutive_pindirs(clock_pio_, clock_sm_, pCLK, 1, true);

    // Start the pre-armed bus detector before CLK starts.
    pio_sm_set_enabled(bus_pio_, bus_sm_, true);
    pio_sm_set_enabled(clock_pio_, clock_sm_, true);
}

void WaitStateBusDriver::begin_reset()
{
    gpio_put(pRESET, false);
}

void WaitStateBusDriver::end_reset()
{
    // Hold for at least eight clocks (and at least 10 us). The Z80 requires
    // three complete clocks, so this leaves margin at any configured rate.
    busy_wait_us_32(reset_hold_us_);

    // Deassert during the low phase, comfortably before the next rising edge.
    while (!gpio_get(pCLK))
        tight_loop_contents();
    while (gpio_get(pCLK))
        tight_loop_contents();
    gpio_put(pRESET, true);
}

BusRequest WaitStateBusDriver::read_request()
{
    return {pio_sm_get_blocking(bus_pio_, bus_sm_)};
}

void WaitStateBusDriver::write_reply(uint32_t reply)
{
    pio_sm_put_blocking(bus_pio_, bus_sm_, reply);
}

} // namespace z80pio

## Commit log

2024-05-29 pcb 2 layer
    [220-1-40-006 3D.STEP, z80_qfn64dip.kicad_pcb, z80_qfn64dip.kicad_sch]
2024-05-30 Pin connections
2024-05-31 add flash and move to 4 layers
    [z80_qfn64dip.kicad_pcb, z80_qfn64dip.kicad_sch]
2024-06-02 hand solder pads for bottom caps, minor tweaks to layout
    [z80_qfn64dip.kicad_pcb, z80_qfn64dip.kicad_sch]
2024-06-03 jtag/spi connector
    [z80_qfn64dip.kicad_pcb, z80_qfn64dip.kicad_sch]
2024-06-05 remove crystal; testpoints connected directly to flash
    [z80_qfn64dip.kicad_pcb, z80_qfn64dip.kicad_sch]
2024-06-05 tweak connections due to changed caravel pinout
    [z80_qfn64dip.kicad_pcb, z80_qfn64dip.kicad_sch]
2024-06-06 update readme pin numbers
2025-05-17 layout tweaks, update to kicad 9
    [z80_qfn64dip.kicad_pcb, z80_qfn64dip.kicad_sch]
2025-05-22 routed and DRC mostly checked
    [DQN0004A.stp, z80_qfn64dip.kicad_pcb, z80_qfn64dip.kicad_sch]
2025-05-22 add zero-ohm resistor for VDDIO as well, fill B with ground, minor changes
    [z80_qfn64dip.kicad_pcb, z80_qfn64dip.kicad_sch]
2025-05-28 minor layout position tweaks; move schematics around a bit; add aisler user design rule
    [z80_qfn64dip.kicad_pcb, z80_qfn64dip.kicad_sch]
2025-05-29 remove signals from power layer moving them to bottom layer; change power routing from tracks to planes if they can be called as such
    [z80_qfn64dip.kicad_pcb, z80_qfn64dip.kicad_sch]
2025-06-03 minor changes
    [z80_qfn64dip.kicad_pcb, z80_qfn64dip.kicad_sch]
2025-07-14 mainly layout changes, remove kicad_prl from comitted files
    [z80_qfn64dip.kicad_pcb, z80_qfn64dip.kicad_sch]
2025-07-14 move everything to front side; label pins
    [z80_qfn64dip.kicad_pcb, z80_qfn64dip.kicad_sch]
2025-10-29 rp2350 driver build files
    [z80_qfn64dip.kicad_pcb]
2025-10-29 pcb: kicad symbols
2025-11-05 building a rp2350 driver using cmake
    [weact-openocd.cfg]
2025-11-06 fix linker script to correctly put crt code at the beginning. z80_boot blinks a pio_led now
    [z80_boot.c]
2025-11-29 fix boot: move crt code to .text.crt0 section to actually make it first in ELF, workaround for a seemingly faulty timer0, copy isr.c. Blinking with style
    [isr.c, main.cpp, z80_boot.c]
2025-12-03 fix assembler invocation. default lax parsing would incorrectly parse 'and a, x' instructions into two. fixes and printint support on IORQ/WR
    [main.cpp]
2025-12-03 something like a ram-test. ported prelim_test and a cpm-style print basic test
2025-12-11 rp2350_driver: DeZog vscode launcher, load code at 0x8000, sjasm support (need to comment/uncomment to switch)
2026-06-14 mezzanine hcl connector to DIP40 adapter
    [DF40C(2.0)-70DS.stp, mezzanine-dip40.kicad_pcb, mezzanine-dip40.kicad_sch]
2026-09-02 Update mezzanine and Z80 QFN hardware designs
    [mezzanine-dip40.kicad_pcb, z80_qfn64dip.kicad_pcb, z80_qfn64dip.kicad_sch]
2026-09-03 rp2350: add selectable Z80 bus backends
    Add manual, WAIT-state, and frozen-clock bus drivers behind a compile-time selection. Add CMake/Makefile build and WeAct OpenOCD/RTT tooling, and update the GPIO layout and memory/I/O request dispatc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
    [rtt.cfg]
2026-09-04 Add backend-aware Z80 reset handling
    [main.cpp, z80_bus_manual.cpp, z80_pio_bus_frozen.cpp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]
2026-09-04 rework trap and CP/M trap setup
    [main.cpp]
2026-09-06 rp2350: fix Z80 WAIT bus handshake
    Pre-arm WAIT, sample coherent qualified cycles, and hold each response until all bus strobes have completed.
    [z80_pio_bus_wait.cpp]
2026-09-06 trap writing on addr 0x4, not 0 as not to disturb reset vector; add peek and dump bus request functions
    [main.cpp]
2026-09-07 add a id string to a bus driver and print it out on startup
2026-09-09 Stabilize Z80 WAIT handshakes across delayed bus replies
    Qualify requests across two clocks, establish read data before releasing
    WAIT, and require two coherent idle samples before accepting another
    transaction. Keep the bus and clock programs on separate PIO blocks.
    Add configurable clock and reply delays, GPIO/DMA capture, a deterministic
    bus stress program, and trace/model regression tools with recorded hardware
    results. Include Z80 console helpers and diagnostic program updates, and
    leave per-request logging disabled by default.
    [main.cpp]
2026-10-05 Add real-board bus capture, timing analysis and stress tools
2026-10-05 Configure VS Code builds and debugging for the async driver
2026-10-11 Ignore stray CMake and Python cache directories in the driver
2026-10-11 Generate the 50 Hz Z80 frame interrupt in hardware
2026-10-11 Render the Spectrum screen to the LCD from core1
    Adds the ULA border/EAR state, an LCD strip renderer fed by PIO/DMA, and a
    PIO T-state counter for the runtime label.
2026-10-11 Boot the Spectrum 128 ROM with banking, display, keyboard and tape
    main.cpp gains ROM slots, 128K RAM paging and screen selection, inlined
    fast memory paths, RTT keyboard/tape polling with reset, core1 display and
    the frame interrupt. clk_sys defaults to 300 MHz with VREG and flash timing
    adjusted. OpenOCD attaches without reset and serves RTT channels 0-2;
    make keyboard / make tape run the host clients.
2026-10-11 Build and debug the Release driver from VS Code
2026-10-15 Post Z80 memory writes without WAIT on the async bus
    The WAIT guard now asserts only on RD or IORQ, so plain memory writes and
    refresh never stall the CPU. The detector posts exact MREQ+WR snapshots to
    the service FIFO with no reply; the RP applies them in bus order, so a
    following read always sees the written value. A pending reset is taken at
    the next synchronous request. PIO0 is exactly full, so the GPIO39 latency
    marker program is removed.
    FPGA benchmarks at 5 MHz: ram_write +15%, PUSH blit +33% (68.9k -> 91.3k
    T/frame), frame_work +7%; reads and I/O unchanged. At 6 MHz every case
    exceeds Pentagon's 71,680 T/frame. The benchmark gains a push_fill case and
    a --z80-hz option.
    Co-Authored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
2026-10-15 Add TR-DOS disks (Beta 128) and the Pentagon 128 menu ROM
    Emulate a Beta 128 interface with TR-DOS 5.03: the DOS ROM replaces 48
    BASIC on an opcode fetch from 3D00..3DFF and leaves on a fetch from RAM;
    its WD1793 ports decode only meanwhile. The WD1793 completes commands at
    once, with 300 rpm index pulses and the Write Track index timeout that
    TR-DOS 5.03's stray FCh command at drive init relies on.
    Up to four TRD images live in the last 4 MiB of flash (1 MiB slots), so
    mounts survive RP resets and reflashing. Uploads program only differing
    4 KiB blocks; TR-DOS writes go through a one-block cache flushed after
    0.5 s of drive inactivity. Flash writes lock out core1 and restore the
    300 MHz QM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
